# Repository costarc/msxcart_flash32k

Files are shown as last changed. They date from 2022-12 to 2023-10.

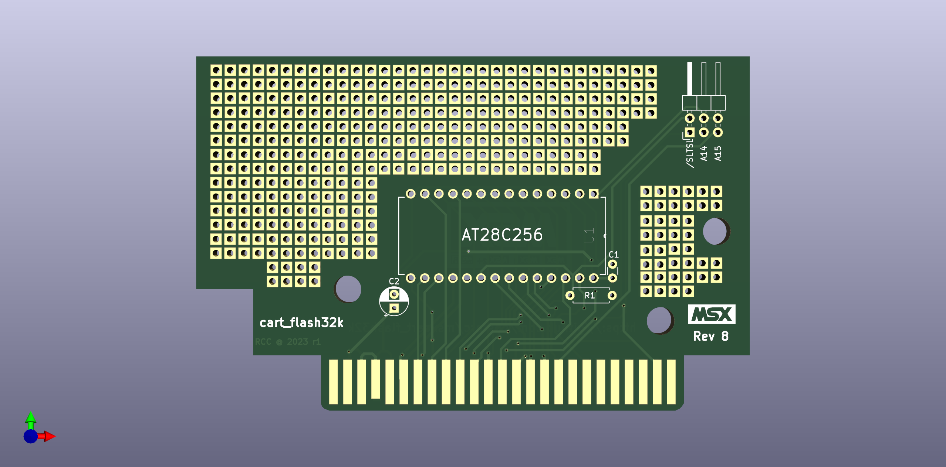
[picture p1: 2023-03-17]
hardware/msx_eeprom.png

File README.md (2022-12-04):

msxcart_flash32k
================
MSX 32K EEPROM cartridge rewritable by software. 

This project contain a schematic and a software for MSX computers.
The schematic is a design to allow writing and reading the AT28C256 EEPROM
(EEPROM = Electronically Rewritable Read Access Memory).

Note on the code to write the EEPROM:

Due to some technical problems to enable/disable the EEPROM Software Data 
Protecion (SDP), the auto detection only works if the SDP was previously disabled.
Make sure the EEPROM SDP has not been enabled by other means, as for example,
using an external EPROM programmer.

The programmer need the slot number where the EEPROM is inserted. You may need to guess the slot (usually it will be 1 or 2),
but for EEPROMs that were previously programmed, it will be displayed using the command:

at28c256.com /i

Note that the slot 1 may not be the top slot in some MSXs. For example, the Canon V-25 slot 1 in on the bottom left side of the micro.

How to write a ROM to the EEPROM:
=================================

PCB Revision 1

1. Close jumpers WR, A15, CS12. All others must be Open
2. Boot the MSX
3. Now close also jumper SLTSL (top jumper)
4. Try to identify the slot where the cartridge is connected with parameter "/i". See Note 1 below.
4. Write the ROM passing the correct slot number in the "/s" parameter, for example: at28c256 /s 1 /f roadfighter.rom)

PCB Revision 0 (with 6 jumpers):

1. Close jumpers WR, A15. All others must be Open
2. Boot the MSX
3. Now close also jumper CS12
4. Try to identify the slot where the cartridge is connected with parameter "/i". See Note 1 below.
4. Write the ROM passing the correct slot number in the "/s" parameter, for example: at28c256 /s 1 /f roadfighter.rom)

PCB Revision 0 with an extra jumper wired up for SLTSL:
Use the same steps described for Revison 1 above.

Boot from the EEPROM
=====================

To boot from the cart, just reboot the MSX.
If you burned 2 ROMs, you can switch between them by moving the jumper between A15 and A14.

Notes:
=====

1: Use "at28c256 /i" to check if the EEPROM slot can be located. 
If there was a previous ROM in the EEPROM, it will be identified  and shown with the initial bytes "41 42". Note that
all other internal expanded slots with some ROM will also be displayed, but with high slot numbers. 
If there was not any ROM previously recorded in your EEPROM, you may need to guess the slot number.

2: The external MSX slots will usually be identified by low numbers such as 01 and 02. Try using parameters "/s 1" or "/s 2" with the at28c256 command to program the EEPROM in these cases where the EEPROM is not located and you have to guess the slot number.

3: Do not remove jumper WR. It should be closed at all times. Write protect is enabled by software by the at28c256.com program.

4: To by-pass the cartridge ROM when it is connected in a slot, remove jumper SLTSL (Revision 1) or CS12 in Revision 0. Insert the jumper back on once the MSX has booted, otherwise the EEPROM will not be enabled for MSX to program it.

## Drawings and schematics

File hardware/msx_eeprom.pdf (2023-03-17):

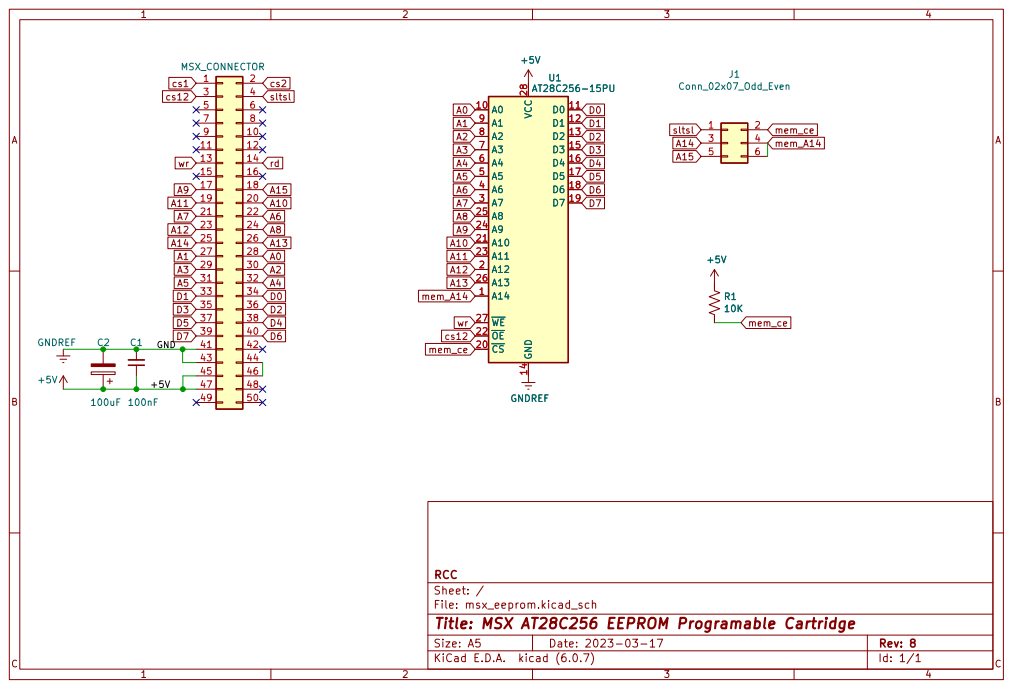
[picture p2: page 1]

Id: 1/1 Title: MSX AT28C256 EEPROM Programable Cartridge

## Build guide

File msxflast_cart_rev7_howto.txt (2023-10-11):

MSX flash_cart PCB Rev 07
=========================

https://github.com/costarc/msxcart_flash32k/

Jumpers:
---- SLTSL
---- A14
---- A15

To write the EEPROM

Download the programmer AT28C256.COM from github repository and save it to your MSX disk.
https://github.com/costarc/msxcart_flash32k/tree/master/software

To write the EEPROM follow these steps:

1. Open /SLTSL (remove jumper)
3. Boot the MSX with the EEPROM cart inserted in the MSX slot
4. Close /SLTSL and A15 (put the jumpers back on)

The MSX slots available to connect cartridges are usually 1 or 2.

AT28C256.COM /i can display your slots, and the initial header in each ROM segment. It might be useful in identifying where the eprom is connected in case you do not know.

Write the ROM to the EEPROM by passing the correct slot number in the "/s" parameter, for example: 

at28c256 /s 1 /f roadfighter.rom

The progress is shown in the screen, and it should take only a few seconds to complete.

To boot from the EEPROM, just reboot the MSX. If you burned 2 ROMs, you can switch between them by moving the jumper between A15 and A14.

You can merge two ROMS to make a single ROM to write to the EEPROM. In a Linux or Mac OS system, this command will do the trick:

cat game1.rom >  big.rom
cat game2.rom >> big.rom

For a Windows/DOS system, you should use something like this:
copy /b game1.rom+game2.rom big.rom

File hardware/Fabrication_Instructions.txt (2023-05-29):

These instrucstions are for PCBWAY.COM
The lines with "=>" are the only ones that must ne changed - the others are default for PCBWAY.

The defaults will work very well, but I recommend to change "Edge Connector" option - see below.
These instructions will result in the cheapest cost (around USD5 for 5 Units)

=> Lenght: 99.90mm, Width: 64.50mm
Layers: 2, Thickness: 1.6mm
Material: FR-4
FR4-TG: TG 150-160
Thickness: 1.6
Min Track/Spacing: 6/6mil
Min Hole Size: 0.3mm
Solder Mask: -> choose what you like, but some places charge more for this option.
Silkscreen: White (change this color if you choose "White Solder Mask")
=> Edge connector: Yes, Bevelling: Yes - 30 Degrees
=> Surface Finish: HASL lead free (change to "immersion gold" at extra cost)

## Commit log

2020-07-01 rev 1
    [msx_eeprom-B_Cu.gbr, msx_eeprom-B_Mask.gbr, msx_eeprom-B_Paste.gbr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]
2020-08-05 Version 1.0 of the writer
    [msx_eeprom-B_Cu.gbr, msx_eeprom-B_Mask.gbr, msx_eeprom-B_Paste.gbr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]
2020-08-05 Added schematic for Kicad 5, and pcb gerbers
    [msx_eeprom.kicad_pcb, msx_eeprom.sch]
2020-08-05 Update schema to Rev.3. Added pull up resistor to /MEM_CE
    [msx_eeprom.kicad_pcb, msx_eeprom.sch]
2020-08-05 revision 3 of schematic
2020-08-07 Moved PCB mounting hole up by 1mm
    [msx_eeprom.kicad_pcb]
2020-08-21 patching ROMS to skip boot when ESC is pressed. Works but needs code on page 1
2020-08-25 Moved jumpers to a position for easier access when connected to MSX
    [msx_eeprom.kicad_pcb, msx_eeprom.sch]
2020-09-02 Updated pcb to rev 5 - moved jumpers to better position
    [msx_eeprom.kicad_pcb, msx_eeprom.sch]
2023-01-05 Imported in Kicad6
    [msx_eeprom.kicad_pcb, msx_eeprom.kicad_sch]
2023-02-28 Rev 7
    [msx_eeprom-B_Cu.gbr, msx_eeprom-B_Mask.gbr, msx_eeprom-B_Paste.gbr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]
2023-03-01 small updates to silk and labels
    [msx_eeprom.kicad_pcb]
2023-03-17 Updated footprint to 2003 r1: pcb holes shiftted a little bit
    [msx_eeprom.kicad_pcb, msx_eeprom.kicad_sch]
2023-12-19 V8a - Added soldermask to edge area.
    [msx_eeprom.kicad_pcb, msx_eeprom.kicad_sch]
2024-05-20 IBOM - Interactive Bill of Materials
    [msx_eeprom.kicad_pcb, msx_eeprom.kicad_sch]
